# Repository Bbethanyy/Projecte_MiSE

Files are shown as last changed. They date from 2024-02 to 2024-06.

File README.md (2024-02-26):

View this project on [CADLAB.io](https://cadlab.io/project/27800). 

# Projecte_MiSE

**Membres del grup:** Bethany Quintero i Rossend Cera
----------------------------------------------------
## Objectiu
Dissenyar un sistema per controlar els moviments de'un Robot mitjançant un Microcontrolador MSP430.

## Elements
- Una placa base amb el Microcontrolador MSP430
- Connexió SBW o JTAG per poder programar/debugar amb una eina externa.
- Un DISPLAY LCD 
- Un Comandament format per un joystick i 1 o 2 polsadors
- El ROBOT 1(DFRobot Mcqueen plus)
- Dues LDRs
- Un mòdul UART<->Wifi

  ## Diagrama de blocs


## Components
| Ref. | Descripció| Datasheet |
| --- | ---| ---|
|MSP430FR2355TPT|Microcontrolador|[Datasheet](https://www.ti.com/lit/ds/symlink/msp430fr2355.pdfts=1708776366062&ref_url=https%253A%252F%252Fwww.ti.com%252Fproduct%252FMSP430FR2355%253Fqgpn%253Dmsp430fr2355)|
|THB-1841844|Joystick| [Datasheet](https://www.mouser.es/datasheet/2/240/thb-3050713.pdf)|
|HD44780U|LCD 1602|[Datasheet](https://www.sparkfun.com/datasheets/LCD/HD44780.pdf)|
|MD21605B6W-FPTLWI3| LCD I2C| [Datasheet](https://www.farnell.com/datasheets/3164276.pdf)|
|MCCOG21605B6W-SPTLYI| LCD Text | [Datasheet](https://www.farnell.com/datasheets/2021773.pdf)|
|NSL-19M51|Detector de fotos| [Datasheet](file:///C:/Users/betha/AppData/Local/Temp/817923a0-e29a-454a-975b-60c01e8ddaef_Documents%20components%20i%20dispositius-20240224.zip.aef/LDR%20NSL-19M51.pdf)|
|...| LMV324| [Datasheet](https://www.ti.com/lit/ds/symlink/lmv324.pdf)|
|...| Trimmer tyco| [Datasheet](https://www.farnell.com/datasheets/314461.pdf)|
|...| Ultrasons HC-SR04| [Datasheet](file:///C:/Users/betha/AppData/Local/Temp/49233692-ea68-4fa0-998a-116c9ef42827_Documents%20components%20i%20dispositius-20240224.zip.827/Ultrasons%20HC-SR04%20Echo%20Locator%20Making%20it%20better.pdf)|
|...| Ultrasons HC-SR05| [Datasheet](file:///C:/Users/betha/AppData/Local/Temp/bb4ae17f-42be-418a-a625-329d45a58329_Documents%20components%20i%20dispositius-20240224.zip.329/Ultrasons%20HC-SR05_Ultrasonic_Module%20VMA306%20Schema.pdf)|
|...| Ultrasons SRF04| [Datasheet](file:///C:/Users/betha/AppData/Local/Temp/166e3fce-a4a8-462c-85ff-759b14133cc4_Documents%20components%20i%20dispositius-20240224.zip.cc4/Ultrasons%20SRF04%20Technical%20Documentation.pdf)|

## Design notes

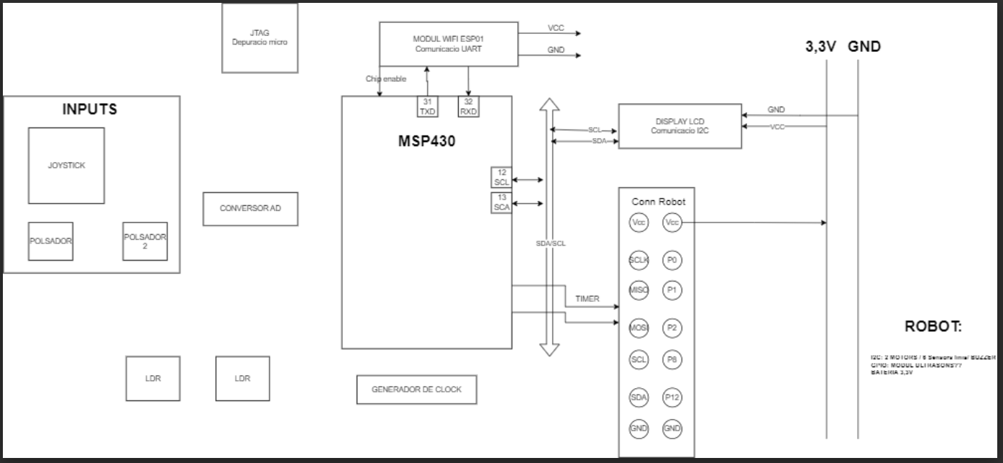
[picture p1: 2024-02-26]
mise.png

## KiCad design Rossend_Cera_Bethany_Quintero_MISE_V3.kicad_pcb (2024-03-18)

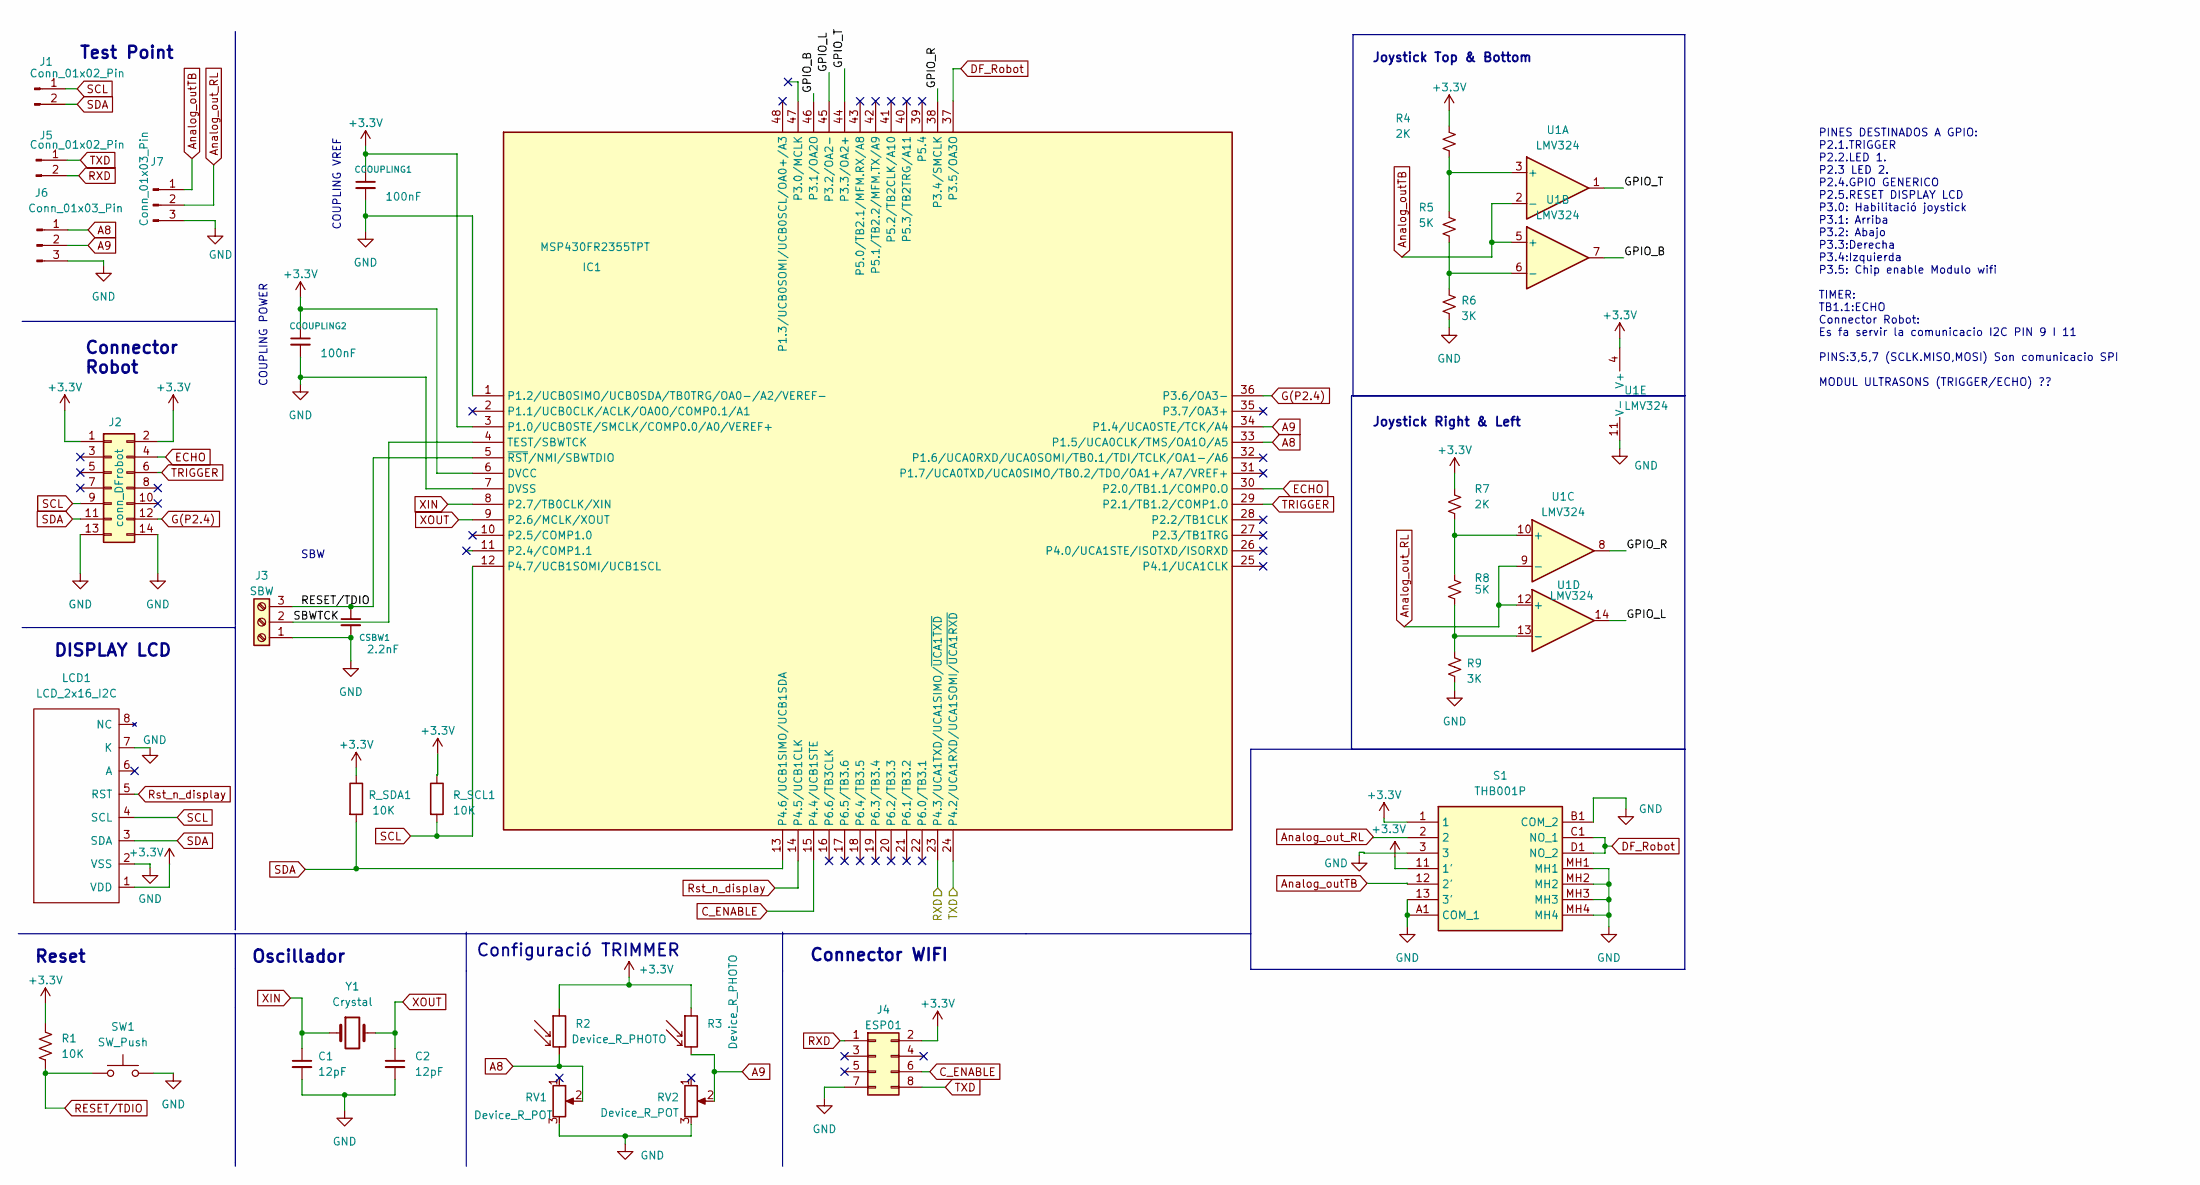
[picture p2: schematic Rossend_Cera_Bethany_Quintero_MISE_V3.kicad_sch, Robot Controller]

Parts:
C1, C2: 12pF; C_0805_2012Metric_Pad1.18x1.45mm_HandSolder
CCOUPLING1, CCOUPLING2: 100nF; C_0805_2012Metric_Pad1.18x1.45mm_HandSolder
CSBW1: 2.2nF; C_0805_2012Metric_Pad1.18x1.45mm_HandSolder
IC1: MSP430FR2355TPT; QFP50P900X900X160-48N; Manufacturer_Part_Number MSP430FR2355TPT; Mouser Part Number 595-MSP430FR2355TPT
J1, J5: Conn_01x02_Pin; PinHeader_1x02_P2.54mm_Vertical
J2: conn_DFrobot
J3: SBW; PinHeader_1x03_P2.54mm_Vertical
J4: ESP01; PinHeader_2x04_P2.54mm_Vertical
J6, J7: Conn_01x03_Pin; PinHeader_1x03_P2.54mm_Vertical
LCD1: LCD_2x16_I2C; LCD_2x16_I2C(Midas)
R1: 10K; R_0805_2012Metric_Pad1.20x1.40mm_HandSolder
R2, R3: Device_R_PHOTO; LDR
R4, R7: 2K; R_0805_2012Metric_Pad1.20x1.40mm_HandSolder
R5, R8: 5K; R_0805_2012Metric_Pad1.20x1.40mm_HandSolder
R6, R9: 3K; R_0805_2012Metric_Pad1.20x1.40mm_HandSolder
RV1, RV2: Device_R_POT; Trimmer_MiSE
R_SCL1: 10K; R_0805_2012Metric_Pad1.20x1.40mm_HandSolder
R_SDA1: 10K; R_0805_2012Metric_Pad1.20x1.40mm_HandSolder
S1: THB001P; Manufacturer_Part_Number THB001P; Mouser Part Number 611-THB001P
SW1: SW_Push; SW_PUSH_6mm
U1: LMV324; SOIC127P600X175-14N
Y1: Crystal; Crystal_C26-LF_D2.1mm_L6.5mm_Horizontal

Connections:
+3.3V: CCOUPLING1.1, CCOUPLING2.1, IC1.3 (P1.0/UCB0STE/SMCLK/COMP0.0/A0/VEREF+), IC1.6 (DVCC), J2.1, J2.2, J4.2, LCD1.1 (VDD), R1.1, R2.1, R3.1, R4.1, R7.1, R_SCL1.1, R_SDA1.1, S1.1, S1.11 (1'), U1.4 (V+)
/GPIO_B: IC1.46 (P3.1/OA2O), U1.7
/GPIO_L: IC1.45 (P3.2/OA2-), U1.14
/GPIO_R: IC1.38 (P3.4/SMCLK), U1.8
/GPIO_T: IC1.44 (P3.3/OA2+), U1.1
/SBWTCK: IC1.4 (TEST/SBWTCK), J3.2
A8: IC1.33 (P1.5/UCA0CLK/TMS/OA1O/A5), J6.1, R2.2, RV1.2
A9: IC1.34 (P1.4/UCA0STE/TCK/A4), J6.2, R3.2, RV2.2
Analog_outTB: J7.1, S1.12 (2'), U1.2 (-), U1.5 (+)
Analog_out_RL: J7.2, S1.2, U1.9 (-), U1.12 (+)
C_ENABLE: IC1.15 (P4.4/UCB1STE), J4.6
DF_Robot: IC1.37 (P3.5/OA3O), S1.C1 (NO_1), S1.D1 (NO_2)
ECHO: IC1.30 (P2.0/TB1.1/COMP0.O), J2.4
G(P2.4): IC1.36 (P3.6/OA3-), J2.12
GND: C1.2, C2.2, CCOUPLING1.2, CCOUPLING2.2, CSBW1.2, IC1.1 (P1.2/UCB0SIMO/UCB0SDA/TB0TRG/OA0-/A2/VE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), IC1.7 (DVSS), J2.13, J2.14, J3.1, J4.7, J6.3, J7.3, LCD1.2 (VSS), LCD1.7 (K), R6.2, R9.2, RV1.3, RV2.3, S1.3, S1.13 (3'), S1.A1 (COM_1), S1.B1 (COM_2), S1.MH1, S1.MH2, S1.MH3, S1.MH4, SW1.2, U1.11 (V-)
unnamed: R4.2, R5.1, U1.3 (+)
unnamed: R5.2, R6.1, U1.6 (-)
unnamed: R7.2, R8.1, U1.10 (+)
unnamed: R8.2, R9.1, U1.13 (-)
RESET/TDIO: CSBW1.1, IC1.5 (~RST/NMI/SBWTDIO), J3.3, R1.2, SW1.1
RXD: IC1.23 (P4.3/UCA1TXD/UCA1SIMO/~UCA1TXD), J4.1, J5.2
Rst_n_display: IC1.14 (P4.5/UCB1CLK), LCD1.5 (RST)
SCL: IC1.12 (P4.7/UCB1SOMI/UCB1SCL), J1.1, J2.9, LCD1.4 (SCL), R_SCL1.2
SDA: IC1.13 (P4.6/UCB1SIMO/UCB1SDA), J1.2, J2.11, LCD1.3 (SDA), R_SDA1.2
TRIGGER: IC1.29 (P2.1/TB1.2/COMP1.O), J2.6
TXD: IC1.24 (P4.2/UCA1RXD/UCA1SOMI/~UCA1RXD), J4.8, J5.1
XIN: C1.1, IC1.8 (P2.7/TB0CLK/XIN), Y1.1
XOUT: C2.1, IC1.9 (P2.6/MCLK/XOUT), Y1.2

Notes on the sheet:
PINES DESTINADOS A GPIO: P2.1.TRIGGER P2.2.LED 1. P2.3 LED 2. P2.4.GPIO GENERICO P2.5.RESET DISPLAY LCD P3.0: Habilitació joystick P3.1: Arriba P3.2: Abajo P3.3:Derecha P3.4:Izquierda P3.5: Chip enable Modulo wifi TIMER: TB1.1:ECHO Connector Robot: Es fa servir la comunicacio I2C PIN 9 I 11 PINS:3,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
Connector Robot
Reset
Oscillador
DISPLAY LCD
Joystick Top & Bottom
Connector WIFI
COUPLING POWER
Configuració TRIMMER
SBW
COUPLING VREF
Test Point
Joystick Right & Left

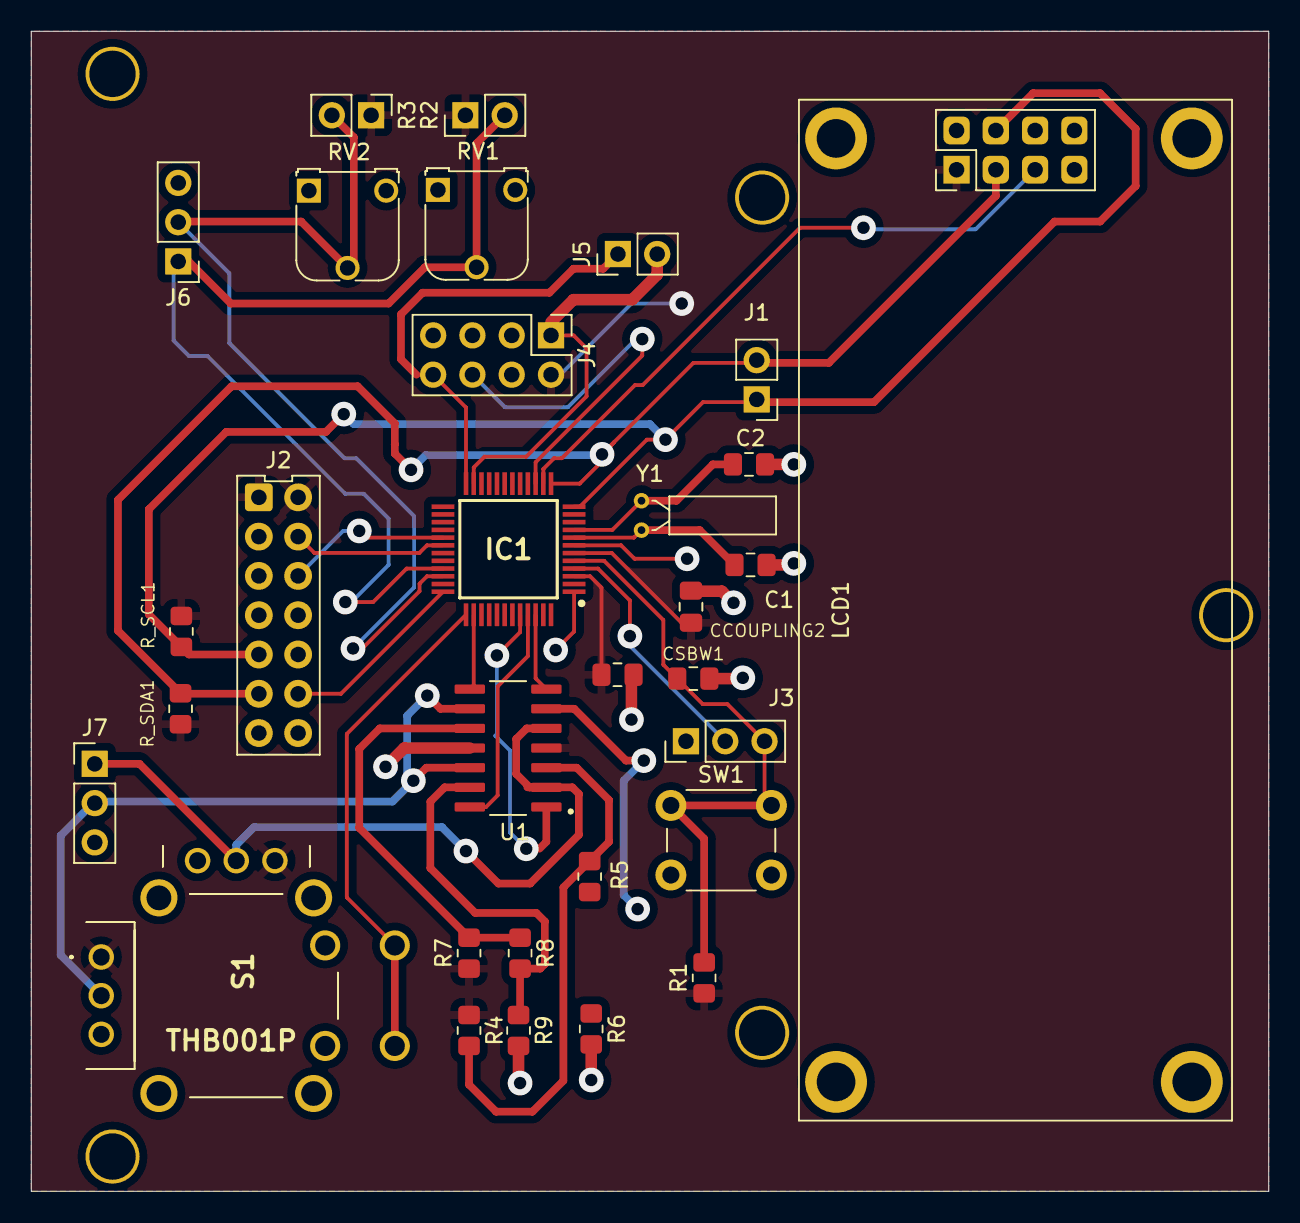
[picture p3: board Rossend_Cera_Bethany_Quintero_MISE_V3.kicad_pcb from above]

Board: 2 copper layers, 80.0 x 75.0 mm, 31 parts (0 on the bottom side), 28 nets.

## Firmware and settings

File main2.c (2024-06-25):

#include <msp430.h>
#include <stdio.h>
#include <stdint.h>
#include <stdlib.h>


#include "clock.h"      //LLIBRERIA QUE CONFIGURA EL RELLOTGE SMCLK
#include "config_i2c.h" //LIBRERIA QUE CONFIGURA LA COMUNICACIÓ I2C
/**
 * main.c
 */

//VARIABLES


//MODO

uint8_t Modo;  //INDICA EL MODE DEL ROBOT
uint8_t Number_moni; //LIMITA A UNA VEGADA LA PANTALLA A GRAFICAR A CADA MODE
uint8_t Mod_cursor;  //INDICA DE FORMA VISUAL ON ES TROBA SITUAT DEL MENU INICIAL 
uint8_t modu_cursor;  //INDICA DE FORMA VISUAL ON ES TROBA SITUAT DEL MENU CONFIG
uint8_t Menu_position; //INDICA EL CURSOR ON ES TROBA SITUAT DEL MENU INICIAL 
uint8_t Menuu_position; //INDICA EL CURSOR ON ES TROBA SITUAT DEL MENU CONFIGURACIÓ

//CONFIG

uint8_t config_velocitat;//VALOR VELOCITAT ESPECIFICAT EN LA CONFIGURACIÓ
uint8_t config_RGB; //VALOR DEL LED ESPECIFICAT EN LA CONFIGURACIÓ


//MOTOR
uint8_t Array_motor[5]; //VARIABLE ENCARREGUADA DE ENVIA LES TRAMES I2C AL MOTOR
uint8_t a;


//ADC
uint16_t conversion_complete;
//DIFERENTS MESURES FETES EN EL ADC
uint16_t resultat_ADC;
uint16_t ilum1;
uint16_t ilum2;
uint8_t update_ADC;

//JOYSTICK
uint16_t J_right;
uint16_t J_bot;


//LCD
uint8_t  Array_LCD[8];//VARIABLE ENCARREGUADA DE ENVIA LES TRAMES I2C PER CONFIGURAT LCD
char  test_LCD[18];   //CARACTERS A REPRESENTAR EN EL DISPLAY
uint8_t longitud;     //NUMERO DE CARACTERS QUE REPRESENTA EL DISPLAY

//LEDS RGB

uint8_t Array_led[2]; //VARIABLE ENCARREGUADA DE ENVIA LA TRAMA I2C DEL LCD


//TIMER
uint32_t captura_temporitzador;
uint8_t  capture_done;  //INDICA SI S'HA FET UNA CAPTURA
uint32_t contador_ms;//NUMERO DE CICLES NECESSARIS PER GENERAR 1MS PER UN SMLCK 16MHZ
uint16_t timer_capture;
uint32_t contador_us; //NUMERO DE CICLES NECESSARIS PER GENERAR 10us PER UN SMLCK 16MHZ
//ULTRASONS
uint16_t ultrasound; //DADE ON S'ALMACENA EL VALOR OBTINGUT DEL ULTRASONS
uint8_t update_ultrasound; //ACTUALITZA EL ULTRASONS
uint16_t comptador; //


//GPIO

uint8_t counter;
uint8_t inputGP;
uint8_t P3_Input;
volatile uint8_t joystick_state = 0; //INDICA I REPRESENTA EL MOVIMENT DEL MOTOR I SI S'ENVA EL MENU INICIAL


void init_GPIO(void){ //INICIALITZACIÓ DELS GPIOS

    //PUERTO 5 P5.2 (RESET de DISPLAY)

    P5SEL0 &= ~0X04;  //S'ESPECIFICA COM A GPIO EL PINT P5.2
    P5SEL1 &= ~0X04;  //S'ESPECIFICA COM A GPIO EL PINT P5.2
    P5DIR  |= 0X04;   //S'ESPECIFICA COM A OUTPUT
    P5OUT  =  0X00;    //LES SORTIDES S'ESPECIFIQUEN A 0

    //PORT P3 (P3.1 (BOTTOM)/P3.2(LEFT)/P3.5(BOTON)//)
    P3SEL0 &= ~0X3E;   //Especifica P3.1 a P3.5 com a GPIO
    P3SEL1 &= ~0X3E;
    P3DIR  &= ~0X3E;   //S'especifica com a input
    P3REN  |= 0X3E;    //Habilitar resistencies pull up
    P3OUT  |= 0X3E;    //pull up


    P3IES  |= 0x3E;
    P3IFG  &=~ 0x3E;   //Creal interrupt flags
    P3IE   = 0X26;    //Habilitar interruptors


    //PORT P4 (4.4//4.5)
    P5SEL0 &=~0X30;   //S'ESPECIFICA COM A GPIO EL PINT P5.2
    P5SEL1 &=~0X30;//S'ESPECIFICA COM A GPIO EL PINT P5.2
    P5DIR  |=0X30; //S'ESPECIFICA COM A OUTPUT
    P5OUT  =0X00;  // LES SORTIDES S'ESPECIFIQUEN A 0

    //PORT 2 (P2.0) TRIGGER/P2.2 BOT /P2.3 RIGHT;
    P2SEL0 &=~0X0D;
    P2SEL0 &=~0X0D;
    P2DIR |=0X0D;
    P2OUT=0X00;

}

void init_ADC(){

    PM5CTL0 &= ~LOCKLPM5; // Disable the GPIO power-on default high-impedance mode
    // to activate previously configured port settings
    P1SEL0 |= BIT5 |BIT4; // Enable A/D channel inputs
    P1SEL1 &= ~(BIT4 |BIT5); // Enable A/D channel inputs
    ADCCTL0 |= ADCON+ADCSHT_2; // Turn on ADC12, S&H=16 clks //En aquet registre actives la conversio //S'haura de activar ADCENC +ADCSC
    ADCCTL1 |= ADCSHP; // ADCLK=MODOSC, //rellotge no extern
    ADCCTL2 &= ~ADCRES; // clear ADCRES in ADCTL
    ADCCTL2 |= ADCRES_2; // 12 bits resolution
    ADCIE = ADCIE0; // Habilita interrupció


}
uint16_t mesura_ADC(uint8_t canal){ //REALITZA UNA MESURA DEL ADC DEL CANAL ESPECIFICAT SINGLE CHANNEL SINGLE CONVERSION
    volatile uint16_t mesura_complete;
    conversion_complete=0;
    if (canal==4)
        ADCMCTL0 |= ADCINCH_4;


    if (canal==5)
        ADCMCTL0 |= ADCINCH_5;

    ADCCTL0 |= ADCENC | ADCSC; //INICIA LA CONVERSIO ADC I EL MOSTREIG

    while(conversion_complete!=1){

    }
    mesura_complete=ADCMEM0; //VARIABLE ON S'ALMACENA EL VALOR DEL ADC
    ADCCTL0 &= ~ADCENC; //Desahabilitem l’ADC per poder canviar de canal
    ADCMCTL0 &= ~0x0F; // Limpia los bits del canal

    return (mesura_complete);

}

uint16_t meas_ADC(uint8_t canal,uint8_t N_valors){ //VALOR PROMITG DE N MESURES DEL ADC
    uint16_t resultat;
    uint8_t i;
    i=0;
    resultat=0;
    for(i=0;i<N_valors;i++){
        resultat=resultat+mesura_ADC(canal)/N_valors;
    }
    return(resultat);

}

//TIMERS CONFIGURACIÓ

void init_timer(){ //timer de 1ms


//INICIALITZACIÓ TIMER TB0
    TB0CTL|=TBSSEL_2; //S'agafa el rellotge SMCLK 16MHZ
    TB0CCTL0|=CCIE_1; //Habilita la interupcio CCIE

    TB0CCR0=16000;    //CONFIGURA A 1mS CONVERSIO DE 16MHZ A 1MS ES EL NUMERO DE POLSOS PERQUE DURI 1ms


    //INICIALITZACIÓ TIMER TB1.2

    //PIN FUNCIó P6.0-> TB1.2 CCIA Capture

    P2SEL0 |= 0X02;
    P2SEL1 &= ~0X02;
    P2OUT=0X00;
    P6DIR  &= ~0X02;

    TB1CTL|=TBSSEL_1; //ACLK CLOCK
    TB1CCTL2|=CM_3|CCIS_0|CCIE_1|CAP_1|SCS_1; //S'OBSERVA EL VALOR DEL BIT DE CAPTURA
    capture_done=0;
    //INICIALITZACIO TIMER TB2

    TB2CTL|=TBSSEL_2; //S'agafa el rellotge SMCLK 16MHZ
    TB2CCTL0|=CCIE_1; //Habilita la interupcio CCIE
    TB2CCR0=16;    //CONFIGURA A 1mS CONVERSIO DE 16MHZ A 1MS ES EL NUMERO DE POLSOS PERQUE DURI 1ms
   //INICIALITZACIÓ TIMER TB3
    TB3CTL|=TBSSEL_2; //S'agafa el rellotge SMCLK 16MHZ
    TB3CCTL0|=CCIE_1; //Habilita la interupcio CCIE
    TB3CCR0=16000;    //CONFIGURA A 1mS CONVERSIO DE 16MHZ A 1MS ES EL NUMERO DE POLSOS PERQUE DURI 1ms


}

void crono_timer(){
    TB3CTL|=MC_1;             //S'habilita mode UP

}

uint16_t captura_timer(){ //CAPTURA EL FLANC DE PUJADA I DE BAIXADA CONTINUAMENT EL TIMER ESTA ACTIVAT MODE CONTINOUS
    uint16_t timer;
    capture_done=0;
//    TB1R=0X0000;
//    TB1CCTL2|=CM_3|CAP_1;
    TB1CTL|=MC_2;


    while(capture_done==0){
       if((TB1CCTL2&COV_1)==COV_1){
           capture_done=1;
       }
    }
    timer=TB1CCR2;

    TB1CTL|=TBCLR; //ES RESETEJA EL VALOR INICIAL DLE COMPTATGE
    TB1CCTL2&=~COV_1;


//    TB1CCTL2&=CM_0;




    return(timer);
}



uint16_t ultrasons(){ //VARIABLE ENCARREGUADA DE OBTINDRE LA DISTANCIA ALS OBSTACLES
    uint16_t trimer1;
    uint16_t trimer2;
    uint16_t temps_obstacle;
    uint16_t distancia;

    //CHECK CAPTURA


    //INICIALITZACIO ULTRASONS TRIGGER
    P2OUT|=0X01;               //Activa el pin 0 del port 2
    delay_us(1);
    P2OUT^=0X01;

    trimer1=captura_timer();   //Captura del temps del primer timer
    trimer2=captura_timer();   //I del segon timer

//
    distancia=33100/32000;                  //    distancia=distancia*343/2;
    distancia=distancia*trimer2/2;          //    temps_obstacle=temps_obstacle/2*32000;
                                            //    distancia=331*temps_obstacle;
    return(distancia);                      //    return(distancia);

}


void delay(uint32_t temps){   //Genera el temps de espera

    contador_ms=0;            //inicialment s'inicialitza a 0
    TB0CTL |= TBCLR;          // Limpiar el contador
    TB0CTL|=MC_1;             //S'habilita mode UP

    while(temps>contador_ms){ //fins que s'hagui fet mes que "temps" de  interupcions surt del bucle
    }
    TB0CTL&=~MC_1;            //PARA EL COMPTADOR

}

void delay_us(uint32_t temps){
    contador_us=0;            //inicialment s'inicialitza a 0
    TB2CTL |= TBCLR;          //Limpiar el contador
    TB2CTL|=MC_1;             //S'habilita mode UP


    while(temps>contador_us){ //fins que s'hagui fet mes que "temps" de  interupcions surt del bucle
    }
    TB2CTL&=~MC_1;            //PARA EL COMPTADOR


}

//CONFIGURACIO_LCD

void init_LCD(){

    P5OUT&=~0X04;        //Es fa un reset del display LCD
    delay(10);           //Temps de espera
    P5OUT|=0x04;         //S'habilita a 1 activant el display LCD
    delay(10);           //temps de espera



//INICIALITZACIO DISPLAY LCD
    Array_LCD[0] = 0x00;       //
    Array_LCD[1] = 0x39;       //
    Array_LCD[2] = 0x14;       //Es configura la freqüencia OSC
    Array_LCD[3] = 0x74;       //Es configura el contrast
    Array_LCD[4] = 0x54;       //POWER ICON
    Array_LCD[5] = 0x6F;       //Follower controller
    Array_LCD[6] = 0x0C;       //S'activa el display
    Array_LCD[7] = 0x01;       //Neteja lo que tenia escrit el display



    I2C_send(0x3E,Array_LCD,8); //S'envia la trama al LCD indicant la adress slave del LCD
    delay(10);

}
void delete_LCD(){ //ELIMINA CONTINGUT DEL LCD
   delay(10);
   Array_LCD[0] = 0x00;       //Initcialitza els primers valors de l'array
   Array_LCD[1] = 0x01;       //
   Array_LCD[2] = 0x20;       //
   Array_LCD[3] = 0x00;       //
   delay(10);
   I2C_send(0x3E,Array_LCD,4);//S'envia la trama al LCD indicant la adress slave del LCD
   delay(10);
}
void move_line(){
  delay(10);
  Array_LCD[0] = 0x00;      //
  Array_LCD[1] = 0x80|0X28; //

  Array_LCD[2]=0x00;
  delay(10);
  I2C_send(0x3E, Array_LCD, 3);
  delay(10);
  }

void move_cursor(uint8_t position){ //1ra linia va de 0x00 a 0x0F  2n linia //0X28//0x37
                                    //2na linia de 0X28 a 0x37
      delay(10);
      Array_LCD[0] = 0x00;          //
      Array_LCD[1] = 0x80|position; //
      Array_LCD[2]=0x00;
      delay(10);
      I2C_send(0x3E, Array_LCD, 3);// Envia la trama al LCD indicant l'adreça slave del LCD
      delay(10);
}

void Menu_moniterització(){                                          //Funció per a visualitzar la monetorització
    move_cursor(0x00);                                               //Mou el cursor a la primera posició
    delay(10);
    longitud = sprintf(test_LCD, "@ DIR=N   VEL=%d",Array_motor[2]); //Escriu la direcció i velocitat al LCD
    I2C_send(0x3E, test_LCD, longitud);                              //Envia al LCD
    delay(10);
    move_cursor(0x28);                                               //Mou el cursor a la 2na linia
    delay(10);
    longitud = sprintf(test_LCD, "@I=       Dis= ",Array_motor[2]);  //Ecriu la Intensitat i Distancia
    I2C_send(0x3E, test_LCD, longitud);                              //Envia al LCD
    move_cursor(0x00);                                               //Cursor a la primera posició
}

void Menu_inicial(){                                                 //Funcio per a la pantalla inicial
    move_cursor(0x00);
    delay(10);
    longitud = sprintf(test_LCD, "@ CONFIG  MANUAL");                //1ra linia Configuració i manual
    I2C_send(0x3E, test_LCD, longitud);
    delay(10);
    move_cursor(0x28);
    delay(10);
    longitud = sprintf(test_LCD, "@ ILUM     DIST ");                //2na linia LDRs i ultrasons
    I2C_send(0x3E, test_LCD, longitud);
    move_cursor(0x00);
}

void Menu_config(){                                                  //Funció per a la configuració inicial
    move_cursor(0x00);
    delay(10);
    longitud = sprintf(test_LCD, "@ VELOCITAT=%d",config_velocitat); //Escriu la velocitat escollida
    I2C_send(0x3E, test_LCD, longitud);
    delay(10);
    move_cursor(0x28);
    delay(10);
    longitud = sprintf(test_LCD, "@ LED RGB=%d",config_RGB);        //Escriu els RGBs escollits
    I2C_send(0x3E, test_LCD, longitud);
    move_cursor(0x00);
}
// ROBOT

//LEDS

leds_RGB(uint8_t izq_led,uint8_t der_led){                         //Modifica el color dels LEDS RGB
    Array_led[0]=0x0B;                                             //S'especifica  del robot el leds RGB
    Array_led[1]=izq_led;                                          //El color del led esquerre
    Array_led[2]=der_led;                                          //El color del led dreta
    I2C_send(0x10,Array_led,3);                                    //S'envia les dades
    delay(10);
}


//MOTOR

//MOTOR: controlar sentiti velocitat de les rodes
mov_motor(uint8_t sentit_1,uint8_t velocitat_1,uint8_t sentit_2,uint8_t velocitat_2){

      Array_motor[0]=0x00;                //Començament per al motor
      Array_motor[1]=sentit_1;            //Assignem el valor sentit_1 a la segona posició de l'array
      Array_motor[2]=velocitat_1;         //la seva velocitat
      Array_motor[3]=sentit_2;            //Sentit_2 per a la quarta posició de l'array
      Array_motor[4]=velocitat_2;         //la seva velocitat
      I2C_send(0x10,Array_motor,5);       //Envia les dades de l'array del motor
      delay(10);
}

void main(void)
{
    WDTCTL = WDTPW | WDTHOLD;               // stop watchdog timer

    //CONFIGURACIO INICIAL
       init_clocks();                        //Inicialitza els clocks
       init_timer();                         //el temporitzador
       init_GPIO();                          //els pins GPIOs
       i2c_init();                           //i el BUS I2C
       init_ADC();                           //Inicialitza ADC
       resultat_ADC=0;                       // Inicialitza la variable resultat_ADC a 0
       counter = 0;                          // Inicialitza el comptador a 0
       joystick_state = 0;                   // Inicialitza l'estat del joystick a 0
       update_ultrasound = 0;                // Inicialitza la variable de control d'actualització d'ultrasons a 0
       comptador = 0;                        // Inicialitza el comptador a 0
       Modo = 0;                             // Inicialitza el mode de funcionament a 0
       Number_moni = 0;                      // Inicialitza la variable Number_moni a 0
       Mod_cursor = 0;                       // Inicialitza la posició del cursor a 0
       Menu_position = 1;                    // Inicialitza la posició del menú a 1
       Menuu_position = 1;                   // Inicialitza la posició del submenú a 1
       config_RGB = 0;                       // Inicialitza la configuració RGB a 0
       config_velocitat = 0;                 // Inicialitza la configuració de velocitat a 0
       update_ultrasound = 1;                // Activa l'actualització d'ultrasons
       update_ADC = 1;                       // Activa l'actualització de l'ADC

    __enable_interrupt();                   //Habilita interrupcions
//    while(1){
//        delay(1000);
//      resultat_ADC=mesura_ADC(4);
//      init_LCD();                        //Inicialitza LCD
//                delay(10);
//                longitud=sprintf(test_LCD,"@%d y \n ",resultat_ADC);  // la paraula velocitat que volem mostrar en la pantalla
//                I2C_send(0x3E,test_LCD,longitud);             //s'envia aquesta dada
//                delay(10);

//    }
//     init_LCD();                        //Inicialitza LCD
//          delay(10);
//          longitud=sprintf(test_LCD,"@HOLA y \n ");  // la paraula velocitat que volem mostrar en la pantalla
//          I2C_send(0x3E,test_LCD,longitud);             //s'envia aquesta dada
//          delay(10);
//          longitud=sprintf(test_LCD,"@ ADIOS"); //Es fa visualitzar en el display LCD el missatge escrit
//          delay(10);
//          I2C_send(0x3E,test_LCD,longitud);
//          delay(10);

//    leds_RGB(1,1);
    //TEST ROBOT

//    while(1){

//          delay(100);
  //        resultat_ADC=meas_ADC(5,10);;
//          resultat_ADC_promitg=meas_ADC(5,10);
//          resultat_ADC= mesura_ADC(4);
//          delay(100);

//      }

//    delay(1000);
//    while(1){
//        delay(100);
//        resultat_ADC=ultrasons();
//        delay(100);

//    }//

    //ES CREA EL MENU DE MONITERITZACIÓ

    init_LCD();     //Inicialitza LCD
    crono_timer();  //Inicialitza el cronometre
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

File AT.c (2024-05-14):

/*
 * AT.c
 *
 *  Created on: 01/2021
 *      Author: C. Serre, UB
 */

#include <msp430.h>
#include <stdio.h>
#include <stdint.h>
#include <string.h>
#include <stdlib.h>


#include "AT.h"
#include LIBUART_AT //#include "uart_wifi.h"

typedef struct Conexion {
    uint8_t IP[16]; //4x3 digitos de IP + 3 puntos + \0 = 16 caracteres
    uint8_t conectado; //1: conectado, 0: no conectado
    uint8_t tipo;   //0: UDP, 1: TCP
    uint8_t conID; //'0'...'9' //El identificador de conexion, lo limitaremos a 1 caracter "0"..."9" = 0x30...0x39. Otro valor si no hay conexion activa
}StrConexion;

uint8_t WiFi_Mode = DEFAULT_MODE; //Modo 1: Station, 2: AP, 3: AP + Station
uint8_t SSID_actual[32]; //El SSID del AP al que estamos conectado.

//Mensajes de comunicacion para uart<->wifi:
const uint8_t echo_OFF[] = {"ATE0\r\n"}; //echoing of AT commands = off
const uint8_t echo_ON[] = {"ATE1\r\n"}; //echoing of AT commands = on
const uint8_t crear_AP[] = {"AT+CWSAP_CUR="}; //Para configurar el ESP como AP. SSID y pwd se definiran en AT.h. El resto en la funcion de creacion del AP

const uint8_t local_IP[] = {"AT+CIFSR\r\n"}; //Pedir propia IP, sea cual sea su papel (AP o STA)
const uint8_t lista_clientes[] = {"AT+CWLIF\r\n"}; //Pide la lista de clientes conectados a nosotros cuando somos AP
const uint8_t test[] = {"AT\r\n"}; //El comando mas basico para comprobar si el modulo responde. Debería contestar "OK"
const uint8_t version[] = {"AT+GMR\r\n"}; //Para comprobar la version de firmware del modulo

const uint8_t modo_Cliente[] = {"AT+CWMODE_CUR=1\r\n"}; //Para configurar el ESP en modo Cliente (o "Station")
const uint8_t conectar_AP[] = {"AT+CWJAP_CUR="}; //SSID y pwd se definiran en AT.h.
const uint8_t el_SSID[] = {"AT+CWJAP_CUR?\r\n"}; //Para preguntar donde estoy conectado como Station.
const uint8_t modo_AP[] = {"AT+CWMODE_CUR=2\r\n"}; //Para configurar el ESP en modo AP
const uint8_t quien_Soy[] = {"AT+CWSAP_CUR?\r\n"}; //Para pedir propio SSID cuando somos AP
const uint8_t modo_multi[] = {"AT+CIPMUX=1\r\n"}; //Activar modo mutli-conexiones (necesario para hacer de servidor)
const uint8_t modo_servidor[] = {"AT+CIPSERVER=1,80\r\n"}; //Activar modo servidor
const uint8_t estado_conexiones[] = {"AT+CIPSTATUS\r\n"}; //Pedir info de la(s) conexion(es) con cliente(s)
const uint8_t opt_lista_APs[] = {"AT+CWLAPOPT=1,3\r\n"}; //Ordenar por potencia de transmision, mostrar solo SSID y encriptacion.
const uint8_t lista_APs[] = {"AT+CWLAP\r\n"}; //Pedir la lista de los APs detectados
StrConexion conexion = {.conID = '0'}; //Una struct para almacenar los datos de una conexion
const uint8_t n_num_caract = 32; //numnero max de caracteres a enviar.
const uint8_t num_caract[] = {"32"}; //forma ASCII del numnero max de caracteres a enviar.
//const uint8_t retorno[] = {"\r\n"}; //0x0d 0x0A
//* No hace falta añadir a las cadenas el caracter nulo "\0" de terminacion,
//* el compilador ya lo hace.

const uint8_t Respuesta_OK [] = "AT OK";
const uint8_t Prefijo[] = "+IPD";

uint8_t get_Modo_Wifi(){
    return WiFi_Mode;
}

/*
 * Funcion para activar/desactivar el eco de los comandos que enviamos al ESP
 */
uint8_t comando_ECHO(uint8_t echo){
    struct RxATReturn respuesta;
    if(echo)
        TxAT(sizeof(echo_ON) - 1,echo_ON);
    else
        TxAT(sizeof(echo_OFF) - 1,echo_OFF);
    //y aqui viene una llamada a RxAT() para leer la respuesta:
    respuesta = RxAT(50);
    if(!respuesta.num_bytes) //no hay una respuesta
        return 0; //error
    else { //supondremos que si hay respuesta, sera "OK"
        return 1; //exito
    }
}

/*
 * Un comando de test "AT".
 * La respuesta deberia ser "OK".
 */
uint8_t comando_AT(){
    struct RxATReturn respuesta;
    TxAT(sizeof(test)-1,test);
    //llamada a RxAT() para leer la respuesta:
    respuesta = RxAT(50);
    if(respuesta.num_bytes) //hay una respuesta
        //supondremos que si hay respuesta, tiene que ser "OK"
        return 1; //exito
    return 0;
}

struct RxATReturn pedir_estado_conexiones(){
    struct RxATReturn respuesta;
    TxAT(sizeof(estado_conexiones)-1,estado_conexiones);
    respuesta = RxAT(20);
    return respuesta;
}

uint8_t getConID(){
    if((conexion.conID >= '0') && (conexion.conID <'9'))
        return conexion.conID; //es una var. global mia
    else return '?';
}

uint8_t getConState(){
	struct RxATReturn respuesta;
	TxAT(sizeof(estado_conexiones)-1, estado_conexiones);
	respuesta = RxAT(50);
	return conexion.conectado;
}
//Pedir propia IP, sea cual sea su papel (AP o STA)
struct RxATReturn pedir_mi_IP(){
    struct RxATReturn respuesta;
    TxAT(sizeof(local_IP)-1, local_IP);
    respuesta = RxAT(50);
    return respuesta;
}

/*
 * Para preguntar donde estoy conectado como Station,
 * o para pedir propio SSID y password cuando somos AP
 */
struct RxATReturn pedir_mi_SSID(){
    struct RxATReturn respuesta;
    respuesta.num_bytes = 0;
    if (WiFi_Mode == MODO_AP)
    	TxAT(sizeof(quien_Soy)-1,quien_Soy);
    else
    	TxAT(sizeof(el_SSID)-1,el_SSID);
    respuesta = RxAT(50);
    return respuesta;
}

/*
 * Funcion para formatear la IP en una cadena adecuada para nuestra pantalla
 * cadena: mensaje a destripar
 * texto: cadena imprimible a devolver
 * max_car: numero max de caracteres a almacenar en *texto
 */
int8_t pinta_IP(uint8_t max_car_linea, uint8_t *cadena, uint8_t *texto){
    uint8_t indice = 0, columna = 0;

//    while (cadena[indice]!= 58 /* buscamos el caracter ":"*/){
    //La cadena deberia contener:
    // IFSR:STAIP,"xxx.xxx.xxx.xxx"
    while (cadena[indice]!= 34 /* buscamos el caracter comillas dobles '"'*/){
        indice++;
        if (indice > RX_BUFFER_SIZE) return ERR_TEXT_OVERFLOW; //indicamos overflow
    }
    columna = 0;
    indice++;
//    while (cadena[indice]!= 34 /*comillas*/){
//        texto[columna] = cadena[indice];
//        indice++;
//        if (indice>RX_BUFFER_SIZE) return ERR_TEXT_OVERFLOW; //Salimos indicando overflow
//        if(columna < max_car_linea) columna++;
//        else return 0; //Si en este punto aun no hemos encontrado las comillas, no es normal, abortamos
//    }
//    indice++;
    while(cadena[indice] != 34 /*comillas*/){ //leemos hasta las segundas comillas
        texto[columna] = cadena[indice];
        indice++;
        if(indice>RX_BUFFER_SIZE) return ERR_TEXT_OVERFLOW;//Salimos indicando overflow
        if(columna < max_car_linea) columna++;
        else break; //El resto de caracteres que no caben en max_car se descartan...
    }
    texto[columna] = 0; //El caracter de terminacion de cadena.
    return columna; //Si llegamos aqui, devolvemos el numero de carecteres guardados
}
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
